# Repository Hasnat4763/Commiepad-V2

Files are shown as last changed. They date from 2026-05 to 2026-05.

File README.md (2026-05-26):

# Commiepad V2

A fully custom designed macro pad.
It is a sequel to my 1st macropad design [Commiepad](https://github.com/Hasnat4763/CommiePad). The 1st one was not working fully as I had made some mistakes in the PCB by not using a matrix and combining OLED SDA with neopixel data line. So I fixed that mistake in this one. It can be used for running macros which can help people like programmers and designers to run commands they need to run a lot just by clicking one key instead of multiple.

# Motivation

As my 1st hackpad design didn't work, and I had some free time, I thought of designing a new hackpad.

## Parts used:  
- SEEED XIAO RP 2040 with custom KMK firmware 
- 8 Cherry MX switches
- EC 11 encoder
- SSD1306 OLED
- Custom desktop app to control underglow and OLED

## Gallery

# PCB

Schematic

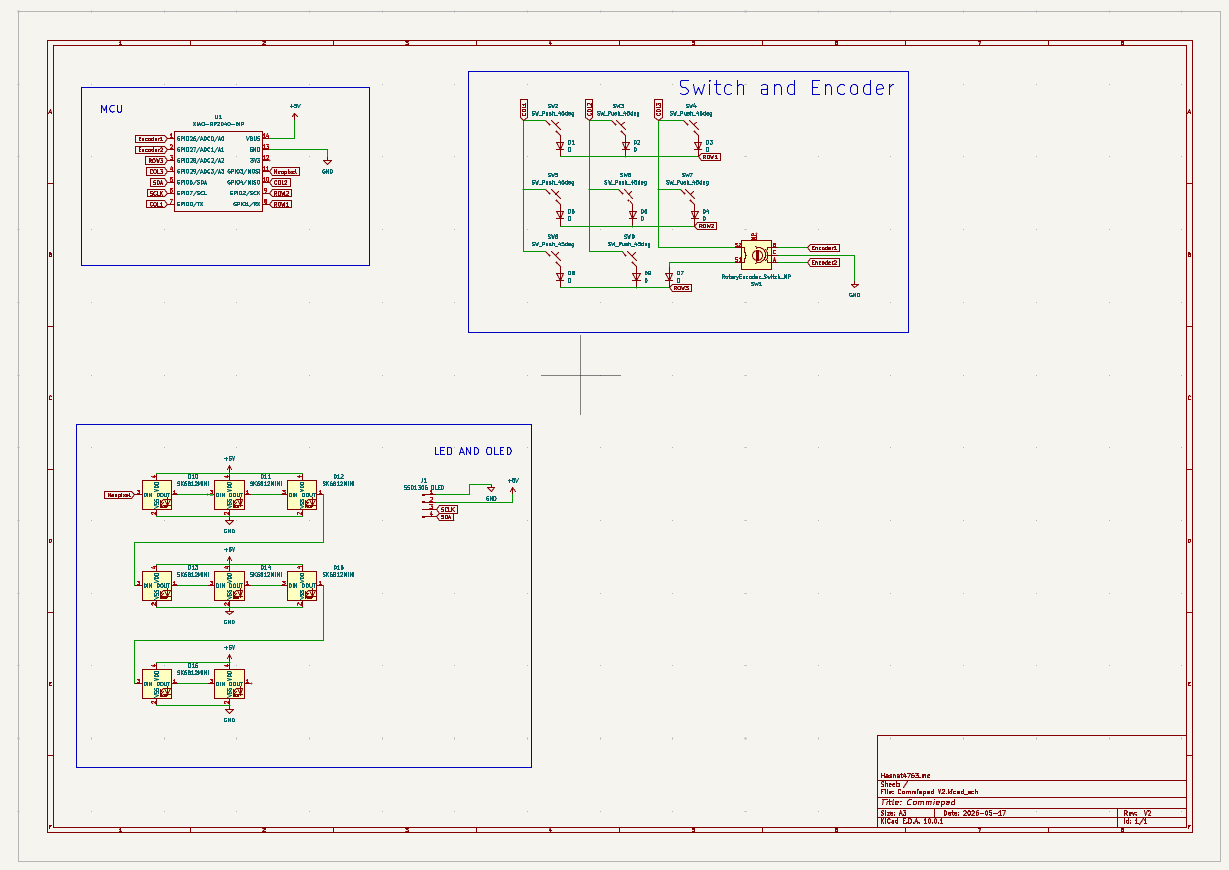
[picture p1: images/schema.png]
Schematic


PCB

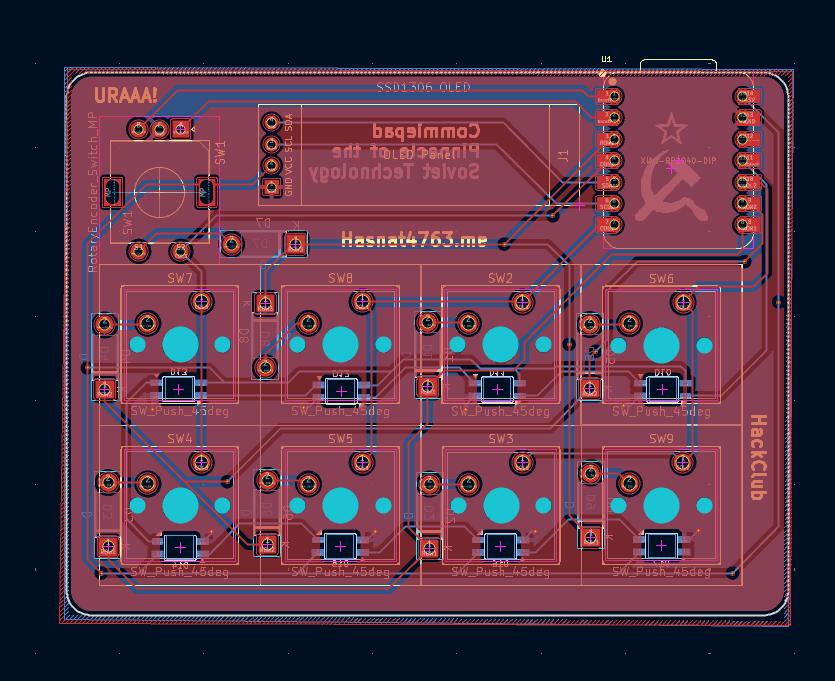
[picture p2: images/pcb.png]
PCB


PCB Rendered

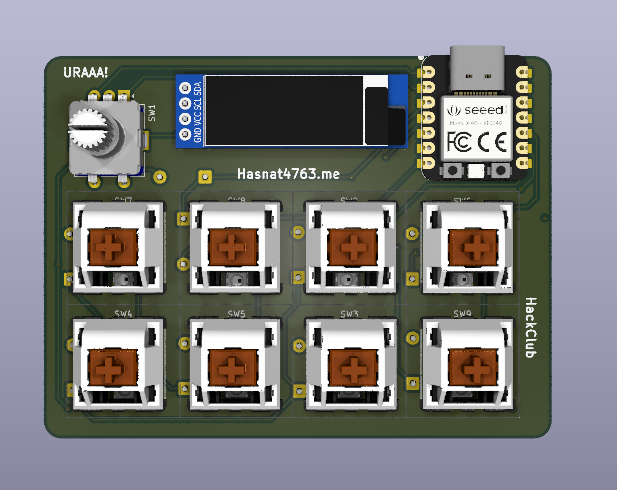
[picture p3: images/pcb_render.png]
PCB Rendered


# CAD

Full Board Assembled

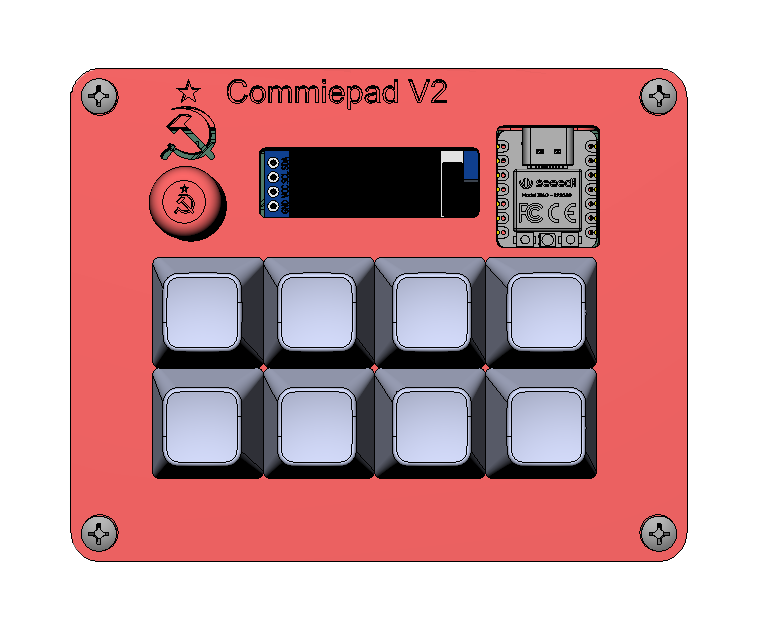
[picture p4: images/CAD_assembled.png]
CAD Fully Assembled


Bottom Part

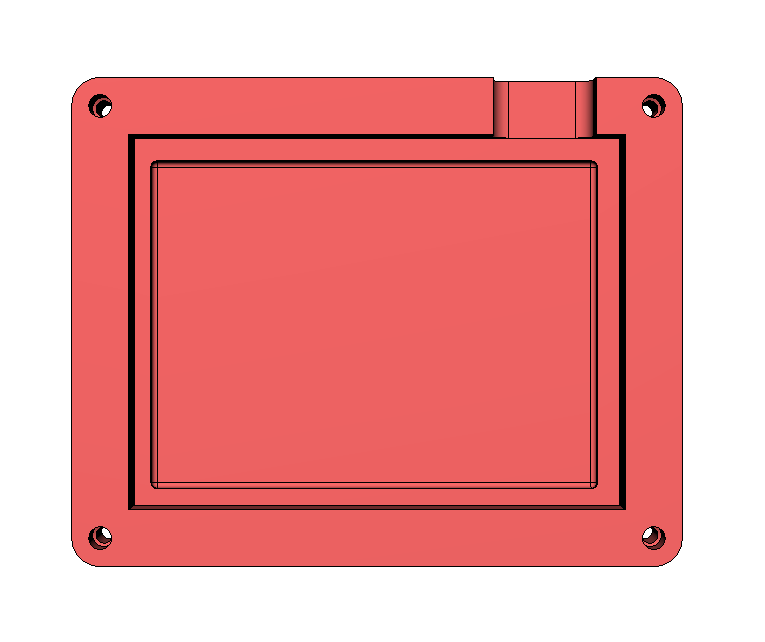
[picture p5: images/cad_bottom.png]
CAD Bottom


Top Cover

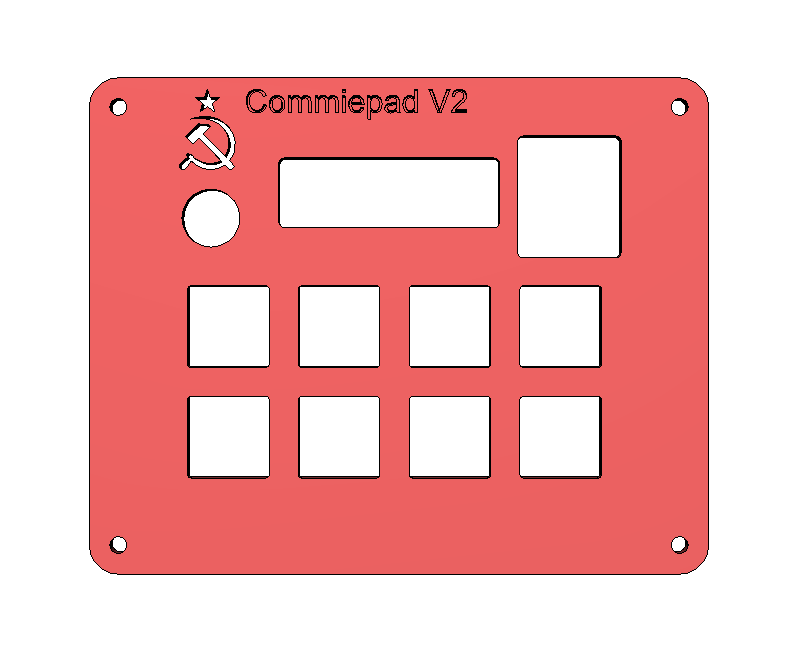
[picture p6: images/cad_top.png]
CAD Top


# Zine Poster

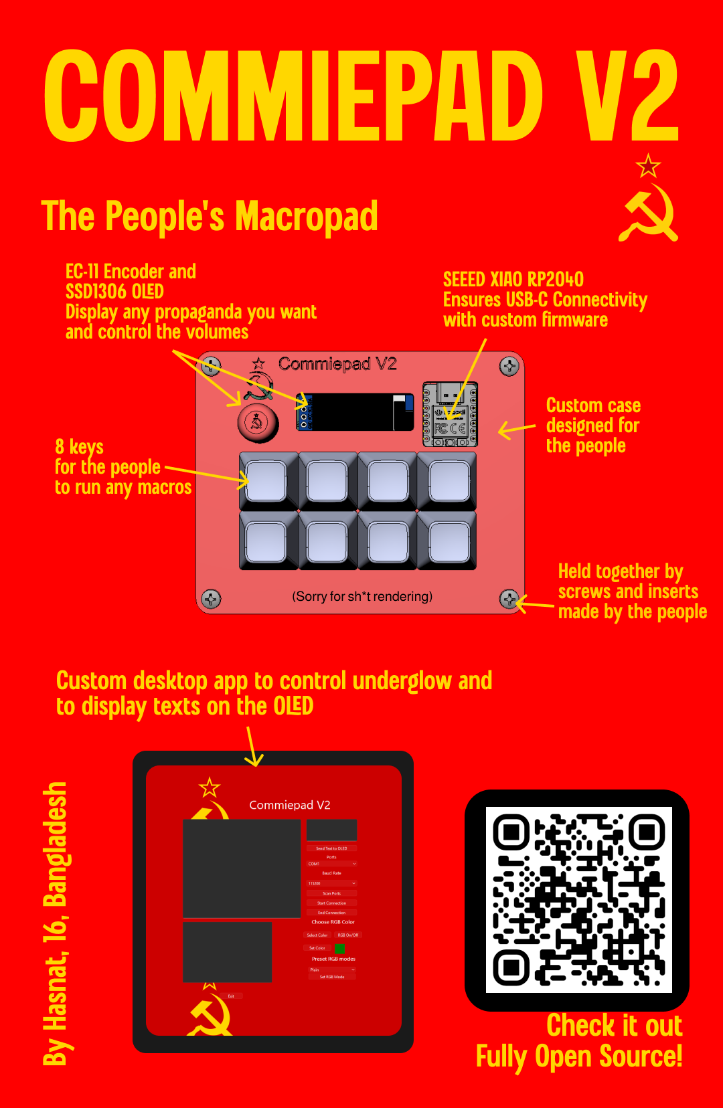
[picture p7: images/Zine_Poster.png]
Zine Poster


# BOM

| Item | Quantity | Price | Link |
|---|---|---|---|
| SEEED XIAO RP2040 (THT) | 1 | $$7.25 | [Link](https://www.seeedstudio.com/XIAO-RP2040-v1-0-p-5026.html) |
| Outemu Silent Peach V3 Switch | 10 | $6.09 | [Link](https://www.aliexpress.com/item/1005006905361113.html) |
| SK6812-MINI-E (RGB LEDs) | 20 | $5.26 | [Link](https://www.aliexpress.com/item/1005005193716172.html) |
| 1N4148 Diode | 100 | $1.20 | [Link](https://www.aliexpress.com/item/4000142272546.html) |
| SSD1306 OLED Display | 1 | $5.15 | [Link](https://www.aliexpress.com/item/1005008640132638.html) |
| YMDK Blank DSA 1u Keycap | 10 | $6.43 | [Link](https://www.aliexpress.com/item/32842379355.html) |
| EC 11 Encoder with Push Button Half Handle 20MM Shaft | 5 | $6.31 | [Link](https://www.aliexpress.com/item/1005005983134515.html) |
| M3 Heat Set Inserts | 30 | $6.13 | [Link](https://www.aliexpress.com/item/1005006071488810.html) |
| M3 Fasteners | 50 | $6.28 | [Link](https://www.aliexpress.com/item/1005011845940916.html) |
| Top Case | 1 | Printing Legion |  |
| Bottom Case | 1 | Printing Legion |  |
| PCB | 5 | $11.02 | JLCPCB |

## Build and Use

# Where to get the PCB

To fabricate the PCB, use any PCB fabricators you can find for cheap, for most people it's JLCPCB. But then you also have to check the shipping cost and customs of your country.
For the parts, aliexpress works. But then you can also get them from your local suppliers too.

# Flashing the firmware

First, follow the [KMK starter guide](https://github.com/KMKfw/kmk_firmware/blob/main/docs/en/Getting_Started.md) to flash KMK on your microcontroller, My repository already has the KMK files necessary with all the extra libraries for the SSD1306 OLED, so you can follow the KMK starter guide but remember to copy the files from this repository instead of the KMK one. Remember to copy the [serialcommand.py](https://github.com/Hasnat4763/Commiepad-V2/blob/c52ac5da764008b54e5d9a0160083da586aadd7f/Commiepad%20V2%20Firmware%20KMK/serialcommand.py) else you won't be able to use the desktop app to control the RGB underglow. You can change the keys you want the macro pad to press on the [main.py](https://github.com/Hasnat4763/Commiepad-V2/blob/aac4e51710a858434e91d4a1d5ed2a7157012af6/Commiepad%20V2%20Firmware%20KMK/main.py), as I have just put some placeholder keys like A, B, C, D etc. for now. You may even make layers so one key can be used to trigger multiple keys!

# Using the desktop app

the desktop app looks like this 

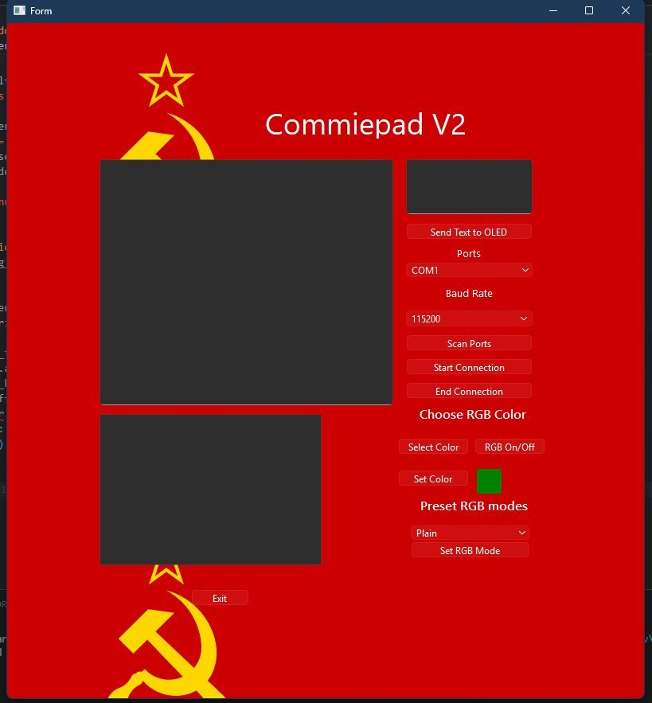
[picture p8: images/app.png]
desktop_app


I have included a build for windows [here](Software/CommiepadV2.exe)

To build for Mac/Linux:

```
# 1. Create virtual environment
python3 -m venv commiepad_env
source commiepad_env/bin/activate

# 2. Install dependencies
pip install -r requirements.txt

# 3. Build executable
pyinstaller --onefile --windowed --add-data "main.ui:." --add-data "bg.png:." --hidden-import=PyQt6.QtCore --hidden-import=PyQt6.QtGui --hidden-import=PyQt6.QtWidgets --hidden-import=PyQt6.uic --name CommiepadV2 main.py

```

After launching the app, select the COM port your Macropad is connected to, and select the baud rate (Most popular option is 115200), after that click the button called "Start Connection". After successful connection, the debug area will show a message about it. Then you can start controlling the RGB and also put text on the OLED from it.

Features of this app:
- Can turn underglow on/off
- Set custom color to it
- Set RGB mode to KMK presets
- Set any text to the OLED

I may add some more features to it later. For now these should work (They haven't been tested yet).

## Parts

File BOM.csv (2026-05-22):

Item | Quantity | Price | Link
SEEED XIAO RP2040 (THT) | 1 | $7.25 | https://www.seeedstudio.com/XIAO-RP2040-v1-0-p-5026.html
Outemu Silent Peach V3 Switch | 10 | $6.09 | https://www.aliexpress.com/item/1005006905361113.html
SK6812-MINI-E (RGB LEDs) | 20 | $5.26 | https://www.aliexpress.com/item/1005005193716172.html
1N4148 Diode | 100 | $1.20 | https://www.aliexpress.com/item/4000142272546.html
SSD1306 OLED Display | 1 | $5.15 | https://www.aliexpress.com/item/1005008640132638.html
YMDK Blank DSA 1u Keycap | 10 | $6.43 | https://www.aliexpress.com/item/32842379355.html
EC 11 Encoder with Push Button Half Handle 20MM Shaft | 5 | $6.31 | https://www.aliexpress.com/item/1005005983134515.html
M3 Heat Set Inserts | 30 | $6.13 | https://www.aliexpress.com/item/1005006071488810.html
M3 Fasteners | 50 | $6.28 | https://www.aliexpress.com/item/1005011845940916.html
Top Case | 1 | Printing Legion
Bottom Case | 1 | Printing Legion
PCB | 5 | $11.02 | JLCPCB

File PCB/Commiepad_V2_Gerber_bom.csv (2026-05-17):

Designator | Footprint | Quantity | Value | LCSC Part #
D1, D2, D3, D4, D5, D6, D7, D8, D9 | D_DO-41_SOD81_P7.62mm_Horizontal | 9 | D
D10, D11, D12, D13, D14, D15, D16, D17 | SK6812-MINI-E | 8 | SK6812MINI
J1 | SSD1306-0.91-OLED-4pin-128x32 | 1 | SSD1306 OLED
SW1 | RotaryEncoder_Alps_EC11E-Switch_Vertical_H20mm | 1 | RotaryEncoder_Switch_MP
SW2, SW3, SW4, SW5, SW6, SW7, SW8, SW9 | SW_Cherry_MX_1.00u_PCB | 8 | SW_Push_45deg
U1 | XIAO-RP2040-DIP | 1 | XIAO-RP2040-DIP

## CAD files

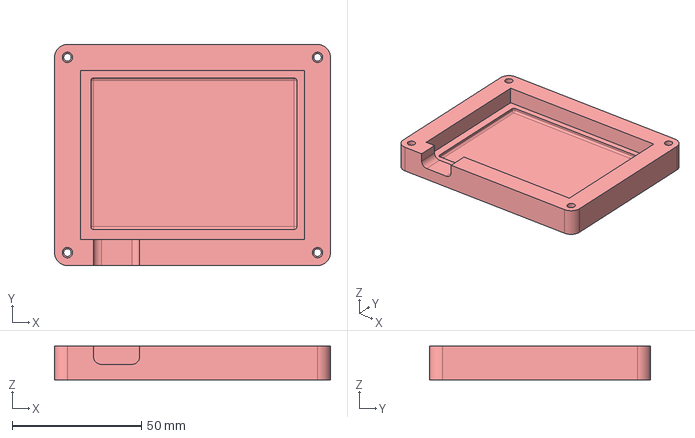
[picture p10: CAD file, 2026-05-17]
CAD/Commiepad V2 Bottom Case.step
106.6 x 85.4 x 13.0 mm

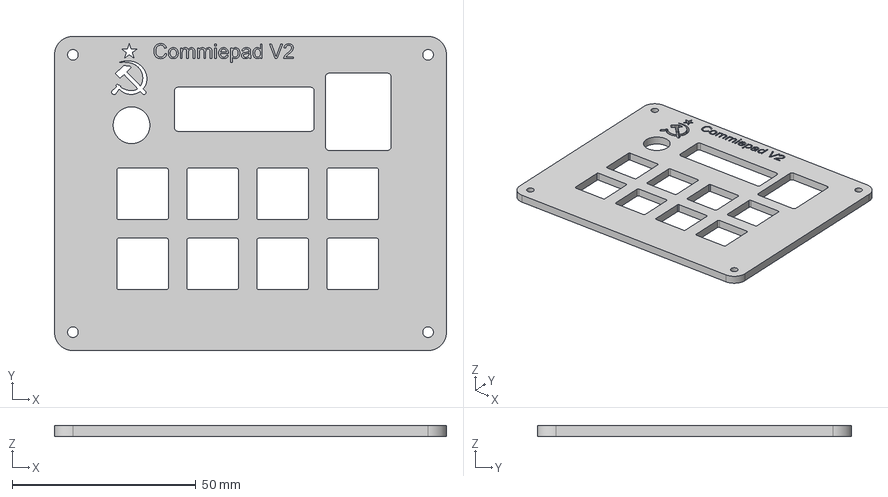
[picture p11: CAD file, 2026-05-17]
CAD/Commiepad V2 Top Plate.step
106.6 x 85.4 x 3.00 mm

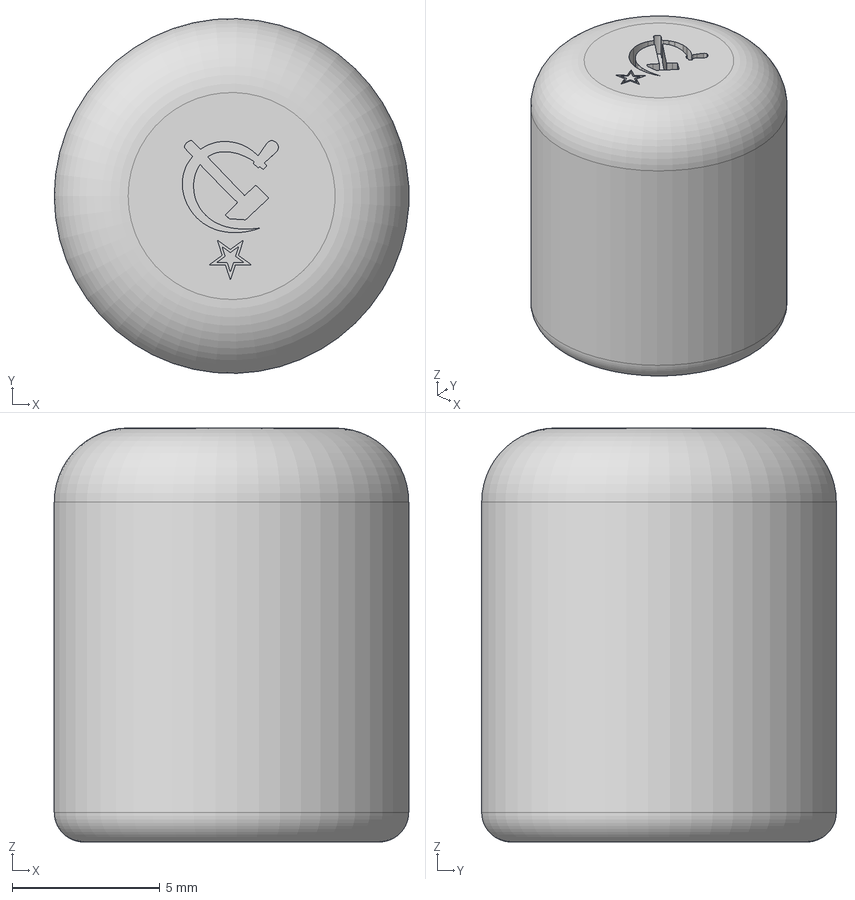
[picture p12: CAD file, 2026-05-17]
CAD/Encoder Cap.step
12.0 x 12.0 x 14.0 mm

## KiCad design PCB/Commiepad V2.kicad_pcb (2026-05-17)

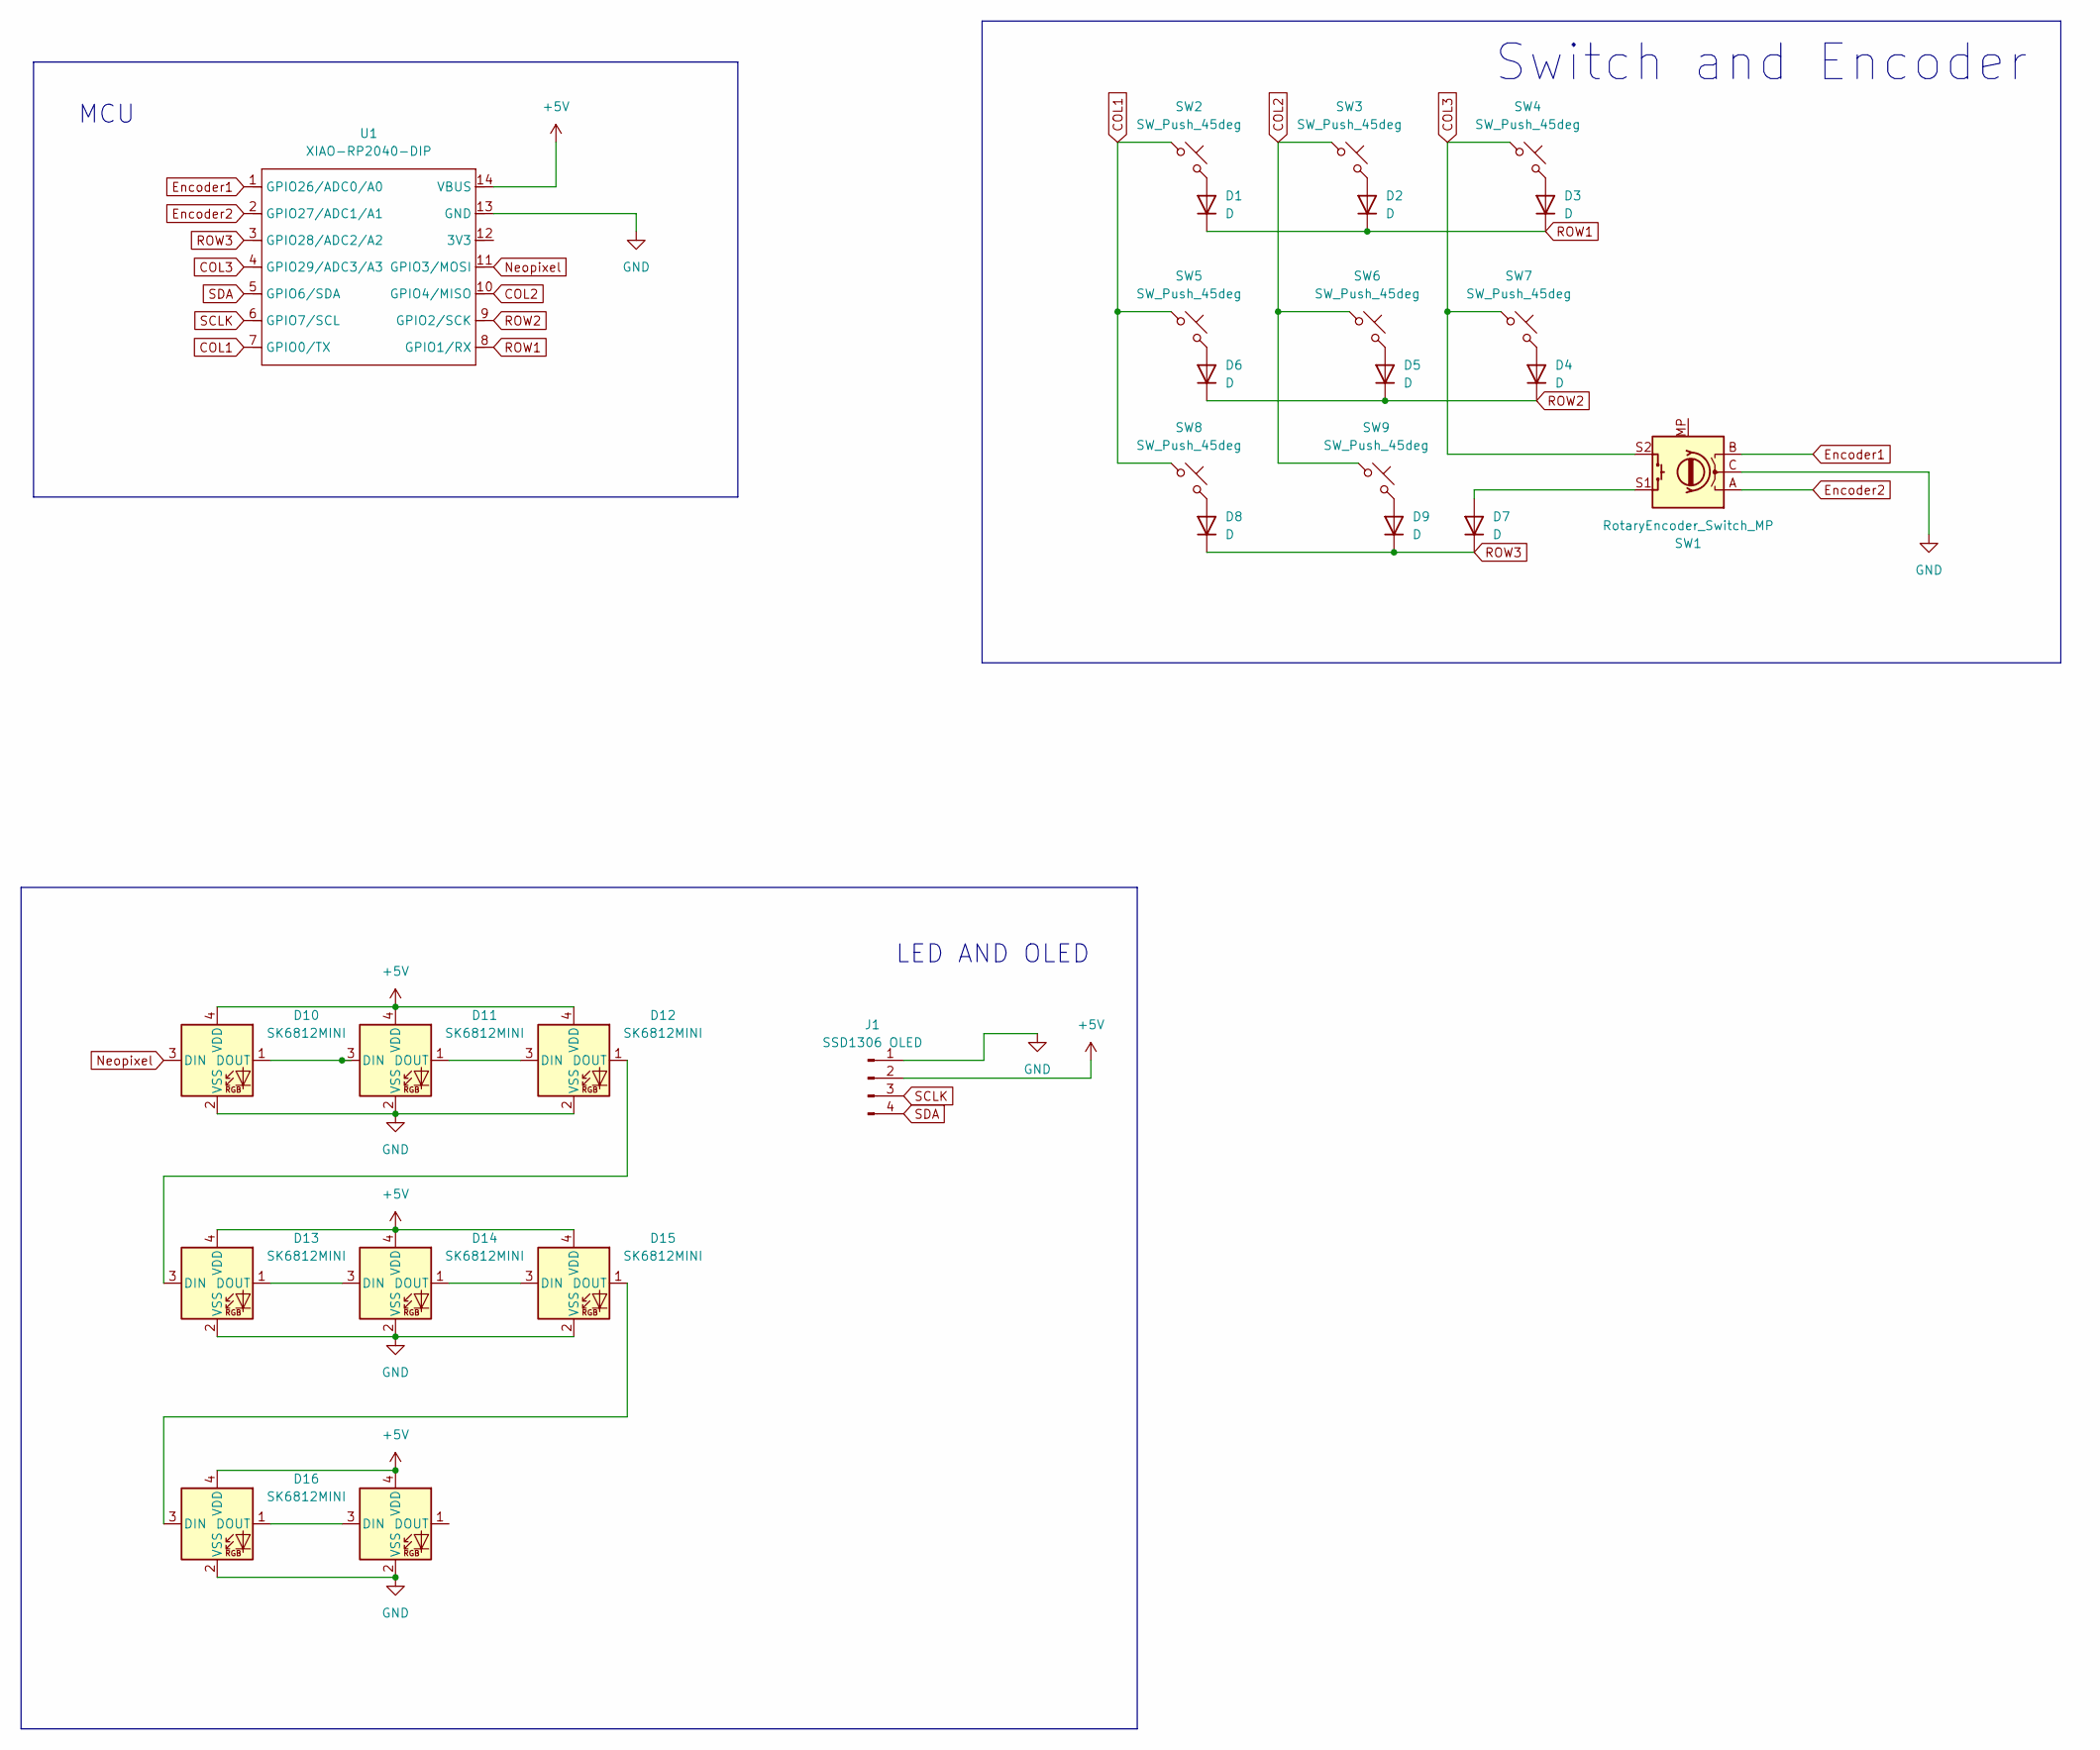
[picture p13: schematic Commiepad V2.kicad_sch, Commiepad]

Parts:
D1, D2, D3, D4, D5, D6, D7, D8, D9: D; D_DO-41_SOD81_P7.62mm_Horizontal
D10, D11, D12, D13, D14, D15, D16, D17: SK6812MINI; SK6812-MINI-E
J1: SSD1306 OLED; SSD1306-0.91-OLED-4pin-128x32
SW1: RotaryEncoder_Switch_MP; RotaryEncoder_Alps_EC11E-Switch_Vertical_H20mm
SW2, SW3, SW4, SW5, SW6, SW7, SW8, SW9: SW_Push_45deg; SW_Cherry_MX_1.00u_PCB
U1: XIAO-RP2040-DIP

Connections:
+5V: D10.4 (VDD), D11.4 (VDD), D12.4 (VDD), D13.4 (VDD), D14.4 (VDD), D15.4 (VDD), D16.4 (VDD), D17.4 (VDD), J1.2, U1.14 (VBUS)
COL1: SW2.1, SW5.1, SW8.1, U1.7 (GPIO0/TX)
COL2: SW3.1, SW6.1, SW9.1, U1.10 (GPIO4/MISO)
COL3: SW1.S2, SW4.1, SW7.1, U1.4 (GPIO29/ADC3/A3)
Encoder1: SW1.B, U1.1 (GPIO26/ADC0/A0)
Encoder2: SW1.A, U1.2 (GPIO27/ADC1/A1)
GND: D10.2 (VSS), D11.2 (VSS), D12.2 (VSS), D13.2 (VSS), D14.2 (VSS), D15.2 (VSS), D16.2 (VSS), D17.2 (VSS), J1.1, SW1.C, U1.13 (GND)
Neopixel: D10.3 (DIN), U1.11 (GPIO3/MOSI)
unnamed: D1.2 (A), SW2.2
unnamed: D2.2 (A), SW3.2
unnamed: D3.2 (A), SW4.2
unnamed: D4.2 (A), SW7.2
unnamed: D5.2 (A), SW6.2
unnamed: D6.2 (A), SW5.2
unnamed: D7.2 (A), SW1.S1
unnamed: D8.2 (A), SW8.2
unnamed: D9.2 (A), SW9.2
unnamed: D10.1 (DOUT), D11.3 (DIN)
unnamed: D11.1 (DOUT), D12.3 (DIN)
unnamed: D12.1 (DOUT), D13.3 (DIN)
unnamed: D13.1 (DOUT), D14.3 (DIN)
unnamed: D14.1 (DOUT), D15.3 (DIN)
unnamed: D15.1 (DOUT), D16.3 (DIN)
unnamed: D16.1 (DOUT), D17.3 (DIN)
ROW1: D1.1 (K), D2.1 (K), D3.1 (K), U1.8 (GPIO1/RX)
ROW2: D4.1 (K), D5.1 (K), D6.1 (K), U1.9 (GPIO2/SCK)
ROW3: D7.1 (K), D8.1 (K), D9.1 (K), U1.3 (GPIO28/ADC2/A2)
SCLK: J1.3, U1.6 (GPIO7/SCL)
SDA: J1.4, U1.5 (GPIO6/SDA)

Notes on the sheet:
Switch and Encoder
LED AND OLED
MCU

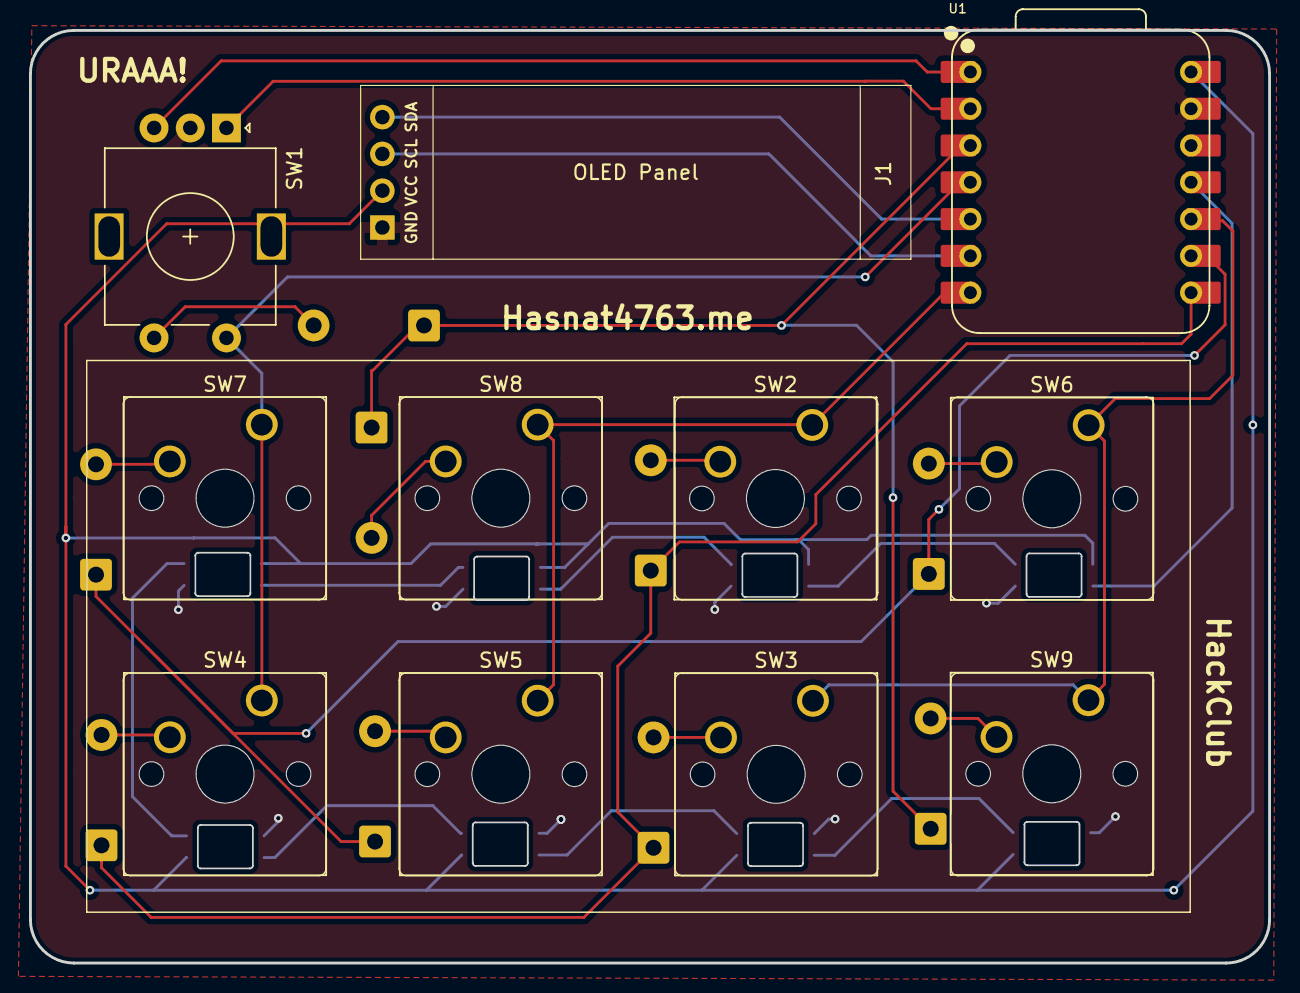
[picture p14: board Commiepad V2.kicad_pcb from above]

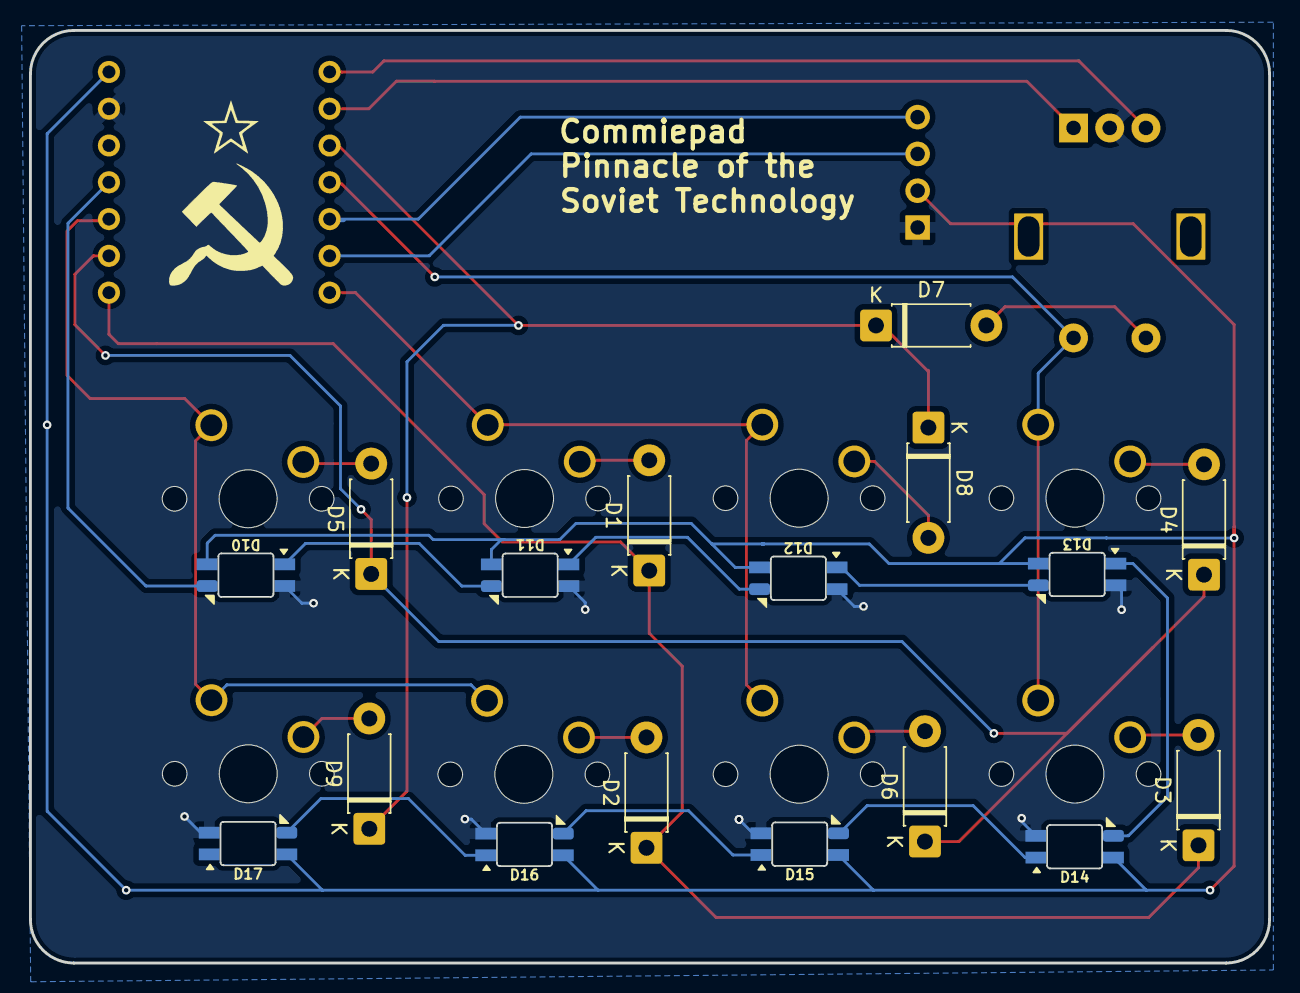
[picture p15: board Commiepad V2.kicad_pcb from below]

Board: 2 copper layers, 85.6 x 64.4 mm, 28 parts (17 on the bottom side), 29 nets.

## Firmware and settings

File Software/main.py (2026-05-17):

import json
import sys
import serial
from serial.tools import list_ports
from PyQt6.uic import loadUi
from PyQt6.QtWidgets import QApplication, QColorDialog, QMainWindow
from PyQt6.QtCore import pyqtSignal
import time
import threading
import os
from queue import Empty, Queue

def resource_path(relative_path):
    try:
        base_path = sys._MEIPASS
    except AttributeError:
        base_path = os.path.dirname(os.path.abspath(__file__))
        
    full_path = os.path.join(base_path, relative_path)
    return full_path


class MainWindow(QMainWindow):
    debug_signal = pyqtSignal(str)
    def __init__(self):
        super().__init__()
        
        ui_path = resource_path("main.ui")
        
        loadUi(ui_path, self)
        
        bg_path = resource_path("bg.png")
        bg_path = resource_path("bg.svg").replace("\\", "/")
        stylesheet = f"""
        #CommiepadV2Controller {{
            background-image: url({bg_path});
            background-repeat: no-repeat;
            background-position: center;
            background-size: cover;
            background-color: #cc0000;
        }}
        """
        self.setStyleSheet(stylesheet)
        
        self.scan_ports.clicked.connect(self.list_serial_ports)
        self.exit.clicked.connect(self.close_app)
        self.select_color.clicked.connect(self.UiComponents)
        self.set_color.clicked.connect(self.set_colors)
        self.ledonoff.clicked.connect(self.toggle_led)
        self.setrgbmode.clicked.connect(self.set_rgb_mode)
        self.serial_init.clicked.connect(self.Serial_init)
        self.oled_text_assign.clicked.connect(self.update_oled_text)
        self.serial_closer.clicked.connect(self.close_serial)
        self.OLED_text
        self.LED_ON = True
        self.RGB_ON_OFF_STATUS.setStyleSheet("background-color: green;")
        self.choose_rgb_mode
        self.baudrate
        self.debug_buffer = []
        self.scanned_ports = None
        self.RGB_Picker
        self.choose_port
        self.debug_browser
        self.RGB_ON_OFF_STATUS
        self.list_serial_ports()
        self.ser = serial.Serial(timeout=1)
        self.write_queue = Queue()
        self.debug_signal.connect(self.debug)
            
    def UiComponents(self):
        color = QColorDialog.getColor()
        if color.isValid():
            self.RGB_Picker.setStyleSheet(f"background-color: {color.name()};")
            r, g, b, _ = color.getRgb()
            self.r = r
            self.g = g
            self.b = b
            self.set_colors()
    def toggle_led(self):
        command = ""
        if not self.ser.is_open:
            self.debug("Serial port not open!")
            return
        if self.LED_ON:
            command = {"type": "keypress", "key": "KC.RGB_TOG"}
            self.LED_ON = False
            self.RGB_ON_OFF_STATUS.setStyleSheet("background-color: red;")
            self.debug("LED turned OFF")
        else:
            command = {"type": "keypress", "key": "KC.RGB_TOG"}
            self.LED_ON = True
            self.RGB_ON_OFF_STATUS.setStyleSheet("background-color: green;")
            self.debug("LED turned ON")
        self.write_queue.put(command)
    def set_rgb_mode(self):
        if not self.ser.is_open:
            self.debug("Serial port not open!")
            return
        mode = self.choose_rgb_mode.currentText()
        command = ""
        if mode.lower() == "plain":
            command = {"type": "keypress", "key": "KC.RGB_MODE_PLAIN"}
            self.debug("Set RGB mode to Plain")
        elif mode.lower() == "breathing":
            command = {"type": "keypress", "key": "KC.RGB_MODE_BREATHE"}
            self.debug("Set RGB mode to Breathing")
        elif mode.lower() == "rainbow":
            command = {"type": "keypress", "key": "KC.RGB_MODE_RAINBOW"}
            self.debug("Set RGB mode to Rainbow")
        elif mode == "Breathing Rainbow":
            command = {"type": "keypress", "key": "KC.RGB_MODE_BREATHE_RAINBOW"}
            self.debug("Set RGB mode to Breathing Rainbow")
        elif mode == "Knight Rider":
            command = {"type": "keypress", "key": "KC.RGB_MODE_KNIGHT"}
            self.debug("Set RGB mode to Knight Rider")
        elif mode.lower() == "swirl":
            command = {"type": "keypress", "key": "KC.RGB_MODE_SWIRL"}
            self.debug("Set RGB mode to Swirl")
        self.write_queue.put(command)
    def update_oled_text(self):
        if not self.ser.is_open:
            self.debug("Serial port not open!")
            return
        text = self.OLED_text.toPlainText()
        self.write_queue.put({"type": "OLED", "text": text})
        self.debug(f"Updated OLED text: {text}")
    def list_serial_ports(self):
        ports = list_ports.comports()
        self.scanned_ports = ports
        self.choose_port.clear()
        for port in self.scanned_ports:
            self.choose_port.addItem(port.device)
    def set_colors(self):
        if not self.ser.is_open:
            self.debug("Serial port not open!")
            return
        self.write_queue.put({"type": "RGB", "r": self.r, "g": self.g, "b": self.b})
        self.debug(f"Set RGB color to: R={self.r}, G={self.g}, B={self.b}")
    def set_serial(self):
        self.ser.port = self.choose_port.currentText()
        self.ser.baudrate = int(self.baudrate.currentText())
        self.debug(f"Selected port: {self.ser.port}, Baudrate: {self.ser.baudrate}")
    def Serial_init(self):
        self.set_serial()
        if self.ser.port is None:
            return
        if not self.ser.port:
            self.debug("No serial port selected!")
            return
        try:
            self.ser.open()
            time.sleep(1)
            self.debug(f"Opened serial port: {self.ser.port}")
            if not hasattr(self, 'serial_writer_thread') or not self.serial_writer_thread.is_alive():
                self.serial_writer_thread = threading.Thread(target=self.serial_write_worker, daemon=True)
                self.serial_writer_thread.start()
        except Exception as e:
            self.debug(f"Error opening serial port: {e}")
    def close_serial(self):
        if self.ser.is_open:
            self.ser.close()
            self.debug(f"Closed serial port: {self.ser.port}")
            self.write_queue.put(None)
            if hasattr(self, 'serial_writer_thread') and self.serial_writer_thread.is_alive():
                self.serial_writer_thread.join(timeout=2)
    def serial_write_worker(self):
        while True:
            try:
                data = self.write_queue.get(timeout=1)
                if data is None:
                    break
                if self.ser.is_open:
                    data = json.dumps(data) + "\n" if isinstance(data, dict) else data
                    self.ser.write(data.encode())
                    self.debug_signal.emit(f"Sent data to serial port: {data}")
                else:
                    continue
            except Empty:
                continue
            except Exception as e:
                self.debug_signal.emit(f"Error writing to serial port: {e}")

    def close_app(self):
        if self.ser.is_open:
            self.close_serial()
        self.close()
    def debug(self, debug_text):
        self.debug_buffer.append(debug_text)
        if len(self.debug_buffer) >= 10:
            self.debug_buffer.pop(0)
        self.debug_browser.setText("\n".join(self.debug_buffer))
if __name__ == "__main__":
    app = QApplication([])
    window = MainWindow()
    window.show()
    app.exec()

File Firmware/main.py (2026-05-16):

import board
import busio
import usb_cdc
from serialcommand import SerialCommand
from kmk.kmk_keyboard import KMKKeyboard
from kmk.keys import KC
from kmk.scanners import DiodeOrientation
from kmk.extensions.RGB import RGB
from kmk.extensions.RGB.animations import AnimationModes
from kmk.extensions.encoder import EncoderHandler
from kmk.extensions.display import Display, TextEntry, ImageEntry
from kmk.extensions.display.ssd1306 import SSD1306



keyboard = KMKKeyboard()

encoder_handler = EncoderHandler()
keyboard.modules.append(encoder_handler)


i2c_bus = busio.I2C(board.SCL, board.SDA)

driver = SSD1306(i2c=i2c_bus, 
                  device_address=0x3C,)

keyboard.col_pins = (board.D6, board.D9, board.D3)
keyboard.row_pins = (board.D7, board.D8, board.D2)
keyboard.diode_orientation = DiodeOrientation.COL2ROW

keyboard.keymap = [
    [KC.A, KC.B, KC.C],
    [KC.D, KC.E, KC.F],
    [KC.G, KC.H, KC.I]
]

encoder_handler.pins = (
    (board.D0, board.D1, None,),
)

encoder_handler.map = (
    (KC.VOLD, KC.VOLU, None,),
)

display = Display(
    display=driver,
    width=128,
    height=32,
    flip=False,
    flip_left=False,
    flip_right=False,
    brightness=0.5
)

display.entries = [
    TextEntry(
        text="Hello, World!", x = 0, y = 0
    )
]

rgb = RGB(pixel_pin=board.D10,
          num_pixels=8,
          rgb_order=(1,0,2),
          val_default=100,
          val_limit=100,
          hue_default=0,
          sat_default=100,
          hue_step=5,
          sat_step=5,
          val_step=5,
          animation_speed=1,
          breathe_center=1,
          bright_effect_length=3,
          animation_mode=AnimationModes.STATIC,
          reverse_animation=False,
          refresh_rate=60
          )

serial_command =  SerialCommand(keyboard=keyboard, RGB=rgb, OLED=display)
keyboard.extensions.append(serial_command)
keyboard.extensions.append(rgb)
keyboard.extensions.append(display)

if __name__ == '__main__':
    keyboard.go()

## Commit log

2026-04-09 Schematic Done
    [Commiepad V2.kicad_pcb, Commiepad V2.kicad_sch]
2026-04-30 Changed the MCU to nRF52840 for wireless connectivity
    [Commiepad V2.kicad_pcb, Commiepad V2.kicad_sch]
2026-05-16 Had to re add everything T_T
    [Commiepad V2.kicad_pcb, Commiepad V2.kicad_sch]
2026-05-16 Moved the PCB source files to a different folder
    [Commiepad V2.kicad_pcb, Commiepad V2.kicad_sch]
2026-05-16 Updated and fixed sum bugs on the desktop app
    [main.py]
2026-05-17 Added PCB, CAD files and edited the README
    [Commiepad V2 Bottom Case.step, Commiepad V2 Top Plate.step, Commiepad V2.kicad_pcb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]
2026-05-17 changed pcb-render to pcb_render
2026-05-17 Trying out Markdown table for BOM
2026-05-17 Adding more info to README.md including BOM
2026-05-17 Updated BOM with new prices and links for components.
2026-05-17 combined the app to one executable for windows
    [Commiepad V2 Bottom Case.step, Commiepad V2 Top Plate.step, Commiepad V2.kicad_pcb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]
2026-05-17 Add instruction to build linux/mac version of app with renaming bom.csv to BOM.csv
2026-05-17 add BOM.csv
2026-05-17 Added bom.csv with gerber extra csvs
    [BOM.csv, Commiepad_V2_Gerber_bom.csv, Commiepad_V2_Gerber_designators.csv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]
2026-05-17 Added links to bom
    [BOM.csv]
2026-05-22 Adding M3 Heat Set Insert and Fasteners to BOM
2026-05-22 Add M3 Heat Set Inserts and M3 Fasteners to BOM
    [BOM.csv]
